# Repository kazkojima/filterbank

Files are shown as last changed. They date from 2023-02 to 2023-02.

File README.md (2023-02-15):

# HF filter bamk

KiCad files for a simple HF filter bank.

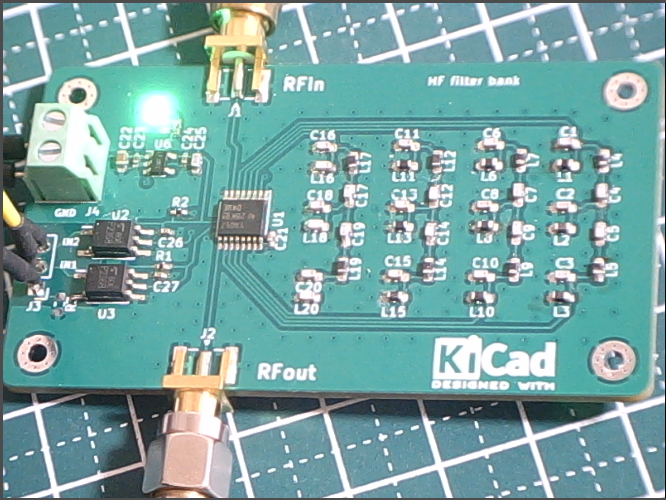
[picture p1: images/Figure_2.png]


There are 4 5-order Chebyshev bandpass filters for 0.5-2, 2-10, 10-28, 28-45MHz.
 [Actual characteristics](https://github.com/kazkojima/filterbank/blob/main/images/Figure_1.png) deviate slightly from target values.

A filter is selected with an analog demultiplexer/multiplexer TS3A5017PWR of which select inputs are drived with photo-isolators.

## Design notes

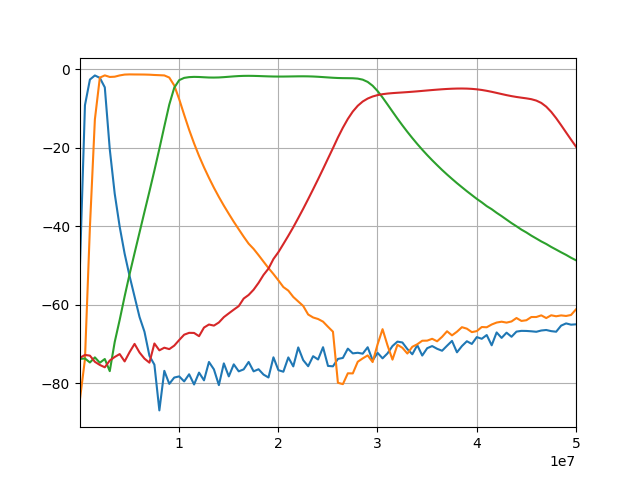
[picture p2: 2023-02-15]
images/Figure_1.png

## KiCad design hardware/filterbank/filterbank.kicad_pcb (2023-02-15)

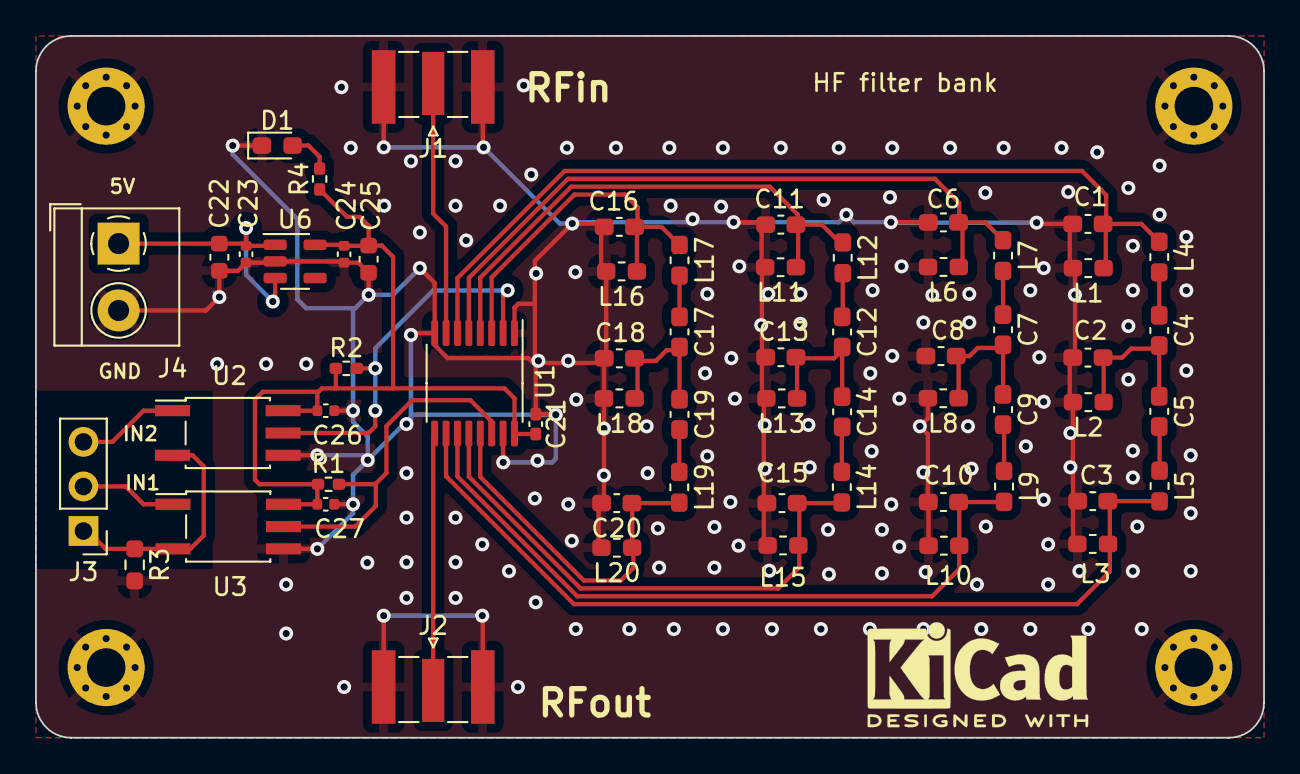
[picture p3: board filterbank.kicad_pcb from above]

Board: 2 copper layers, 70.0 x 40.0 mm, 64 parts (0 on the bottom side), 31 nets.

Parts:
C1, C3: 2200p; C_0603_1608Metric_Pad1.08x0.95mm_HandSolder
C2: 3900p; C_0603_1608Metric_Pad1.08x0.95mm_HandSolder
C4, C5: 3300p; C_0603_1608Metric_Pad1.08x0.95mm_HandSolder
C6, C10: 470p; C_0603_1608Metric_Pad1.08x0.95mm_HandSolder
C7, C9: 1000p; C_0603_1608Metric_Pad1.08x0.95mm_HandSolder
C8: 820p; C_0603_1608Metric_Pad1.08x0.95mm_HandSolder
C11, C15, C16, C20: 180p; C_0603_1608Metric_Pad1.08x0.95mm_HandSolder
C12, C14: 150p; C_0603_1608Metric_Pad1.08x0.95mm_HandSolder
C13, C18: 330p; C_0603_1608Metric_Pad1.08x0.95mm_HandSolder
C17, C19: 33p; C_0603_1608Metric_Pad1.08x0.95mm_HandSolder
C21: 0.1u; C_0402_1005Metric_Pad0.74x0.62mm_HandSolder
C22, C25: 10u; C_0603_1608Metric
C23, C24: 1u; C_0402_1005Metric
C26, C27: 0.1u; C_0402_1005Metric
D1: LED_Filled; LED_0603_1608Metric_Pad1.05x0.95mm_HandSolder
H1, H2, H3, H4: MountingHole_Pad; MountingHole_2.2mm_M2_Pad_Via
J1, J2: Conn_Coaxial; SMA_Samtec_SMA-J-P-X-ST-EM1_EdgeMount
J3: Conn_01x03; PinHeader_1x03_P2.54mm_Vertical
J4: Screw_Terminal_01x02; TerminalBlock3.81mm
L1, L3: 10uH; L_0603_1608Metric_Pad1.05x0.95mm_HandSolder
L2: 5.6uH; L_0603_1608Metric_Pad1.05x0.95mm_HandSolder
L4, L5: 6.8uH; L_0603_1608Metric_Pad1.05x0.95mm_HandSolder
L6, L10: 2.7uH; L_0603_1608Metric_Pad1.05x0.95mm_HandSolder
L7, L8, L9: 1.5uH; L_0603_1608Metric_Pad1.05x0.95mm_HandSolder
L11, L15: 470nH; L_0603_1608Metric_Pad1.05x0.95mm_HandSolder
L12, L14, L17, L19: 560nH; L_0603_1608Metric_Pad1.05x0.95mm_HandSolder
L13: 270nH; L_0603_1608Metric_Pad1.05x0.95mm_HandSolder
L16, L20: 100nH; L_0603_1608Metric_Pad1.05x0.95mm_HandSolder
L18: 56nH; L_0603_1608Metric_Pad1.05x0.95mm_HandSolder
R1, R2: 4.99k; R_0402_1005Metric_Pad0.72x0.64mm_HandSolder
R3: 10M; R_0603_1608Metric_Pad0.98x0.95mm_HandSolder
R4: 3k; R_0402_1005Metric_Pad0.72x0.64mm_HandSolder
U1: TS3A5017PWR; TSSOP-16_4.4x5mm_P0.65mm
U2, U3: TLP2368; SO-5_4.4x3.6mm_P1.27mm
U6: ADP151AUJZ-3.3; TSOT-23-5

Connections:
+3V3: C21.2, C24.1, C25.1, C26.1, C27.1, R1.1, R2.1, R4.1, U1.16 (V+), U2.6 (VDD), U3.6 (VDD), U6.5 (VOUT)
F1OUT: C3.1, L3.1, L5.2, U1.10 (2S1)
F2OUT: C10.1, L9.2, L10.1, U1.11 (2S2)
F3OUT: C15.1, L14.2, L15.1, U1.12 (2S3)
F4OUT: C20.1, L19.2, L20.1, U1.13 (2S4)
GND: C1.2, C2.2, C3.2, C6.2, C8.2, C10.2, C11.2, C13.2, C15.2, C16.2, C18.2, C20.2, C21.1, C22.2, C23.2, C24.2, C25.2, C26.2, C27.2, D1.1 (K), H1.1, H2.1, H3.1, H4.1, J1.2 (Ext), J2.2 (Ext), J4.2, L1.2, L2.2, L3.2, L6.2, L8.2, L10.2, L11.2, L13.2, L15.2, L16.2, L18.2, L20.2, R3.2, U1.1 (1~EN), U1.8 (GND), U1.15 (2~EN), U2.4 (GND), U3.4 (GND), U6.2 (GND)
unnamed: C2.1, C4.2, C5.1, L2.1
unnamed: C4.1, L4.2
unnamed: C5.2, L5.1
unnamed: C7.1, L7.2
unnamed: C7.2, C8.1, C9.1, L8.1
unnamed: C9.2, L9.1
unnamed: C12.1, L12.2
unnamed: C12.2, C13.1, C14.1, L13.1
unnamed: C14.2, L14.1
unnamed: C17.1, L17.2
unnamed: C17.2, C18.1, C19.1, L18.1
unnamed: C19.2, L19.1
unnamed: D1.2 (A), R4.2
unnamed: J1.1 (In), U1.7 (1D)
unnamed: J2.1 (In), U1.9 (2D)
unnamed: J3.1, R3.1, U2.3 (K), U3.3 (K)
unnamed: J3.2, U3.1 (A)
unnamed: J3.3, U2.1 (A)
unnamed: C22.1, C23.1, J4.1, U6.1 (VIN), U6.3 (EN)
unnamed: C1.1, L1.1, L4.1, U1.6 (1S1)
unnamed: C6.1, L6.1, L7.1, U1.5 (1S2)
unnamed: C11.1, L11.1, L12.1, U1.4 (1S3)
unnamed: C16.1, L16.1, L17.1, U1.3 (1S4)
unnamed: R1.2, U1.14 (IN1), U3.5 (VO)
unnamed: R2.2, U1.2 (IN2), U2.5 (VO)
